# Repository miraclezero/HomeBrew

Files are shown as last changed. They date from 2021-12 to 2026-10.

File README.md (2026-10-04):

# HomeBrew

> Raspberry Pi based hardware and software for independently tracking oral operant self-administration behavior in up to four rats.

HomeBrew coordinates RFID identification, active and inactive spout events, syringe-pump movement, visual indicators, session configuration, and data recording. It is intended for experiments involving orally delivered solutions such as sucrose, alcohol, or opioids.

## Highlights

- Tracks as many as four animals independently
- Uses RFID values to identify commands and animals
- Records active and inactive behavioral events
- Controls a stepper-driven syringe pump
- Supports manual pump positioning with forward and backward controls
- Includes limit-switch protection and LED/pixel-ring feedback
- Stores session settings and pump calibration values
- Provides separate test versions of the main and operant programs
- Includes scripts for network checks and recovery from empty Python files
- Includes OpenSCAD files for project-related fabricated parts

## Repository Layout

```text
HomeBrew/
├── openscad/          # OpenSCAD models for mechanical/fabricated components
├── python/            # Experiment control, hardware control, and data collection
├── utility_script/    # Startup, integrity-check, and maintenance scripts
├── wifi-network/      # Network-related configuration or support files
├── .gitignore
└── README.md
```

## System Overview

The software is divided into two long-running responsibilities:

1. **Session controller** — `main.py` or `main_test.py`
2. **Operant controller** — `operant.py` or `operant_test.py`

The session controller reads a configured command RFID, collects the animals' RFID values, allows pump positioning during setup, and starts the operant controller as a subprocess. The session controller remains active afterward so it can continue identifying animals at the active and inactive spouts.

```mermaid
flowchart TD
    A[Start main.py] --> B[Select session]
    B --> C[Scan command RFID]
    C --> D[pump calibration /optional/]
    D --> E[Adjust pump position]
    E --> F[Scan animal RFID tags]
    F --> G[Disable manual adjustment]
    G --> H[Start operant.py subprocess]
    H --> I[Monitor active and inactive RFID events]
    H --> J[Monitor lick and operant inputs]
    I --> K[Write animal-specific event records]
    J --> K
    J --> L[Deliver configured reward]
```

## Main Software Components

### `main.py` / `main_test.py`

The main entry point is responsible for:

- reading session commands
- scanning animal RFID tags
- managing the pump-positioning period
- launching the operant program
- continuing to monitor RFID input while the operant process runs
- writing active and inactive identification records

The test variant is intended for development or hardware validation. Confirm its behavior against the production script before relying on it during an experiment.

### `operant.py` / `operant_test.py`

The operant program is launched by the main program with the information required for the selected session. It manages operant events and saves recorded data to the corresponding output files.

### `pump_move.py`

This module provides a higher-level `PumpMove` abstraction over Raspberry Pi GPIO control. Its movement method drives the stepper motor forward or backward.

The motor outputs must be disabled after use. Leaving the driver energized can cause unnecessary heating.

### `RatActivityCounter`

Animal activity values, including active and inactive licking or related events, are represented through `RatActivityCounter` instances.

### Pump calibration

The calibration program compensates for changes in the relationship between motor steps and delivered volume. The operator measures the actual amount dispensed, enters that value, and the software recalculates the step setting.

Calibrate whenever the syringe, tubing, mechanical drive, solution, or pump geometry changes, and verify the resulting volume with repeated measurements.

## Experiment Workflow

1. Power the Raspberry Pi and connected hardware.
2. Confirm network status if the installation depends on network access.
3. Start the main program.
4. Scan a command RFID configured in `session_configuration.csv`.
5. Position the syringe pump before finalizing setup.
6. Scan the RFID tag for each animal assigned to the session.
7. Allow the main program to launch the operant process.
8. Monitor the apparatus and verify that active/inactive events are attributed correctly.
9. At the end of the session, confirm that all expected output files were written and safely stop the hardware.

The current logic distinguishes active and inactive RFID input by identifier length: eight characters for active input and ten characters for inactive input. Because identifier length is part of the input protocol, RFID readers and tags must be tested with the exact deployed configuration.

## Configuration

The existing code expects configuration in absolute Raspberry Pi paths.

| File | Purpose |
|---|---|
| `/home/pi/homebrew_config.json` | Stores the device ID, session number/ID, and stepper-motor step size. The session number is incremented when the program starts. |
| `/home/pi/openbehavior/HomeBrew/python/session_configuration.csv` | Defines session information and command RFID mappings. |
| `/home/pi/openbehavior/HomeBrew/python/config.py` | Centralizes directory paths and provides `get_sessioninfo(sessionid)` for reading session data from the CSV file. |

Clone this repository to the Raspberry Pi:

```bash
git clone https://github.com/miraclezero/HomeBrew.git
cd HomeBrew
```

Start the main program

```bash
cd python
python3 main_test.py
```

## Hardware

The documented setup uses the following major components:

- Raspberry Pi
- DRV8834 low-voltage stepper-motor driver
- stepper motor
- external 3–12V power adapter
- Adafruit MPR121 12-key capacitive-touch sensor
- forward and backward limit switches
- forward and backward push buttons
- pixel ring
- active and inactive LEDs
- RFID readers/antennas used by the experiment
- syringe-pump mechanism

## GPIO and Wiring Reference

All GPIO values below use **BCM numbering**, as implied by the existing documentation. Confirm this convention in the code before wiring.

### Stepper Motor Driver — DRV8834

| Driver pin | Connection |
|---|---|
| `VMOT` | Positive terminal of the external power adapter |
| `GND` | Negative terminal of the external power adapter |
| `B2`, `B1`, `A1`, `A2` | Stepper motor wires: black, green, red, and blue, respectively |
| Logic `GND` | Any Raspberry Pi ground pin |
| `M0`, `M1` | GPIO 17 and GPIO 22 |
| `SLP` | Any Raspberry Pi 3.3V pin |
| `STEP` | GPIO 6 |
| `DIR` | GPIO 26 |

The listed motor wire colors may not apply to every motor. Identify coil pairs from the motor documentation or with a meter before connecting the driver.

### Capacitive-Touch Sensor — MPR121

| MPR121 pin | Connection |
|---|---|
| `SCL` | GPIO 3 / I²C clock |
| `SDA` | GPIO 2 / I²C data |
| `3Vo` | Any Raspberry Pi 3.3V pin |
| `GND` | Any Raspberry Pi ground pin |
| `0` | Inactive-contact wire |
| `1` | Active-contact wire |

### Limit Switches

| Switch terminal | Connection |
|---|---|
| Normally Open (`NO`) | Raspberry Pi 5V connection, red wire |
| Forward contact (`C`) | GPIO 24, green wire |
| Backward contact (`C`) | GPIO 23, white wire |

### Manual Pump Buttons

| Control | Connection |
|---|---|
| Forward button | GPIO 5 |
| Backward button | GPIO 27 |
| GND connect with resistor | Any Raspberry Pi ground pin  |

### Pixel Ring

| Pixel-ring pin | Connection |
|---|---|
| `IN` | GPIO 18 |
| `GND` | Any Raspberry Pi ground pin |
| `5V DC` | Any Raspberry Pi 5 V pin |

Check the ring's maximum current demand before powering it from the Raspberry Pi header.

### Status LEDs

| LED | Connection |
|---|---|
| Active LED | GPIO 16 |
| Inactive LED | GPIO 19 |
| GND connect with resistor | Any Raspberry Pi ground pin |

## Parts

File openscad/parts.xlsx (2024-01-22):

Item | Part | Quantity | Supplier | Link
Pump Parts | Pump power | 1 | Amazon | https://www.amazon.com/Belker-Adjustable-Universal-Household-Electronics/dp/B07NKZCWT1
 | NEMA 17 Stepper Motor | 1 | Pololu | https://www.pololu.com/product/2267
 | 12" Actobotics Channel | 1 | ServoCity | https://www.servocity.com/12-0-channel
 | Actobotics Side Tapped Pattern Mount B | 1 | ServoCity | https://www.servocity.com/90-quad-hub-mount-b
 | Actobotics NEMA 17 Stepper Mount | 1 | ServoCity | https://www.servocity.com/nema-17-stepper-motor-mount
 | Pump rod | 1 | Amazon | https://www.amazon.com/uxcell-Stainless-Copper-Thread-Printer/dp/B07R1H5ZMV?s=industrial
 | Rod bearing | 1 | Amazon | https://www.amazon.com/Bearings-Double-Shielded-Miniature-Skateboard/dp/B07H83VV6B
 | Rod coupling | 1 | Amazon | https://www.amazon.com/AFUNTA-Flexible-Couplings-Compatible-Machines/dp/B07JL1QYLS
 | 4 pin connector | 1 | Amazon | https://www.amazon.com/mxuteuk-Female-Connector-Adapter-Electrical/dp/B083GR7FQF
 | 3 pin connector | 1 | Amazon | https://www.amazon.com/BTF-LIGHTING-Connectors-WS2812B-WS2811-WS2812/dp/B01DC0KIT2
 | Limit Switch with Lever 2 Pack | 1 | ServoCity | https://www.servocity.com/spdt-miniature-lever-snap-action-micro-switch-2-pack
Box Parts | Raspberry Pi 3B | 1 | Rasperrypi | https://www.raspberrypi.com/
 | Pi screen | 1 | Dfrobot | https://www.dfrobot.com/product-1784.html
 | Pololu DRV8825 Stepper Motor Driver | 1 | Pololu | https://www.pololu.com/product/2133
 | Touch sensor board | 1 | Adafruit | https://www.adafruit.com/product/1982
 | Button | 1 | Amazon | https://www.amazon.com/Gikfun-12x12x7-3-Tactile-Momentary-Arduino/dp/B01E38OS7K
 | Button board | 1 | Amazon | https://www.amazon.com/LAMPVPATH-Prototype-Breadboard-Universal-Printed/dp/B07JDZDPVQ
 | Led light | 1 | Amazon | https://www.amazon.com/100pcs-Ultra-Bright-Emitting-Diffused/dp/B01GE4WGTS?th=1
 | Rfid scanner | 1 | Amazon | https://www.amazon.com/YARONGTECH-125khz-reader-EM4100-desktop/dp/B078TK8KYL/?th=1
 | connector cables | 1 | Amazon | https://www.amazon.com/Antrader-Breadboard-Dupont-Arduino-Raspberry/dp/B07RXK9SLW?th=1
 | Resistor(200ohm, 1/2w) | 1 | Amazon | https://www.amazon.com/EDGELEC-Resistor-Tolerance-Multiple-Resistance/dp/B07QDXV1KF
Other Parts | 30 cc Syringe 10 pack | 1 | Amazon | https://www.amazon.com/Easy-Glide-30CC-Syringe-Sterile/dp/B08HV25ZN2
 | screw and nuts (#6-32)

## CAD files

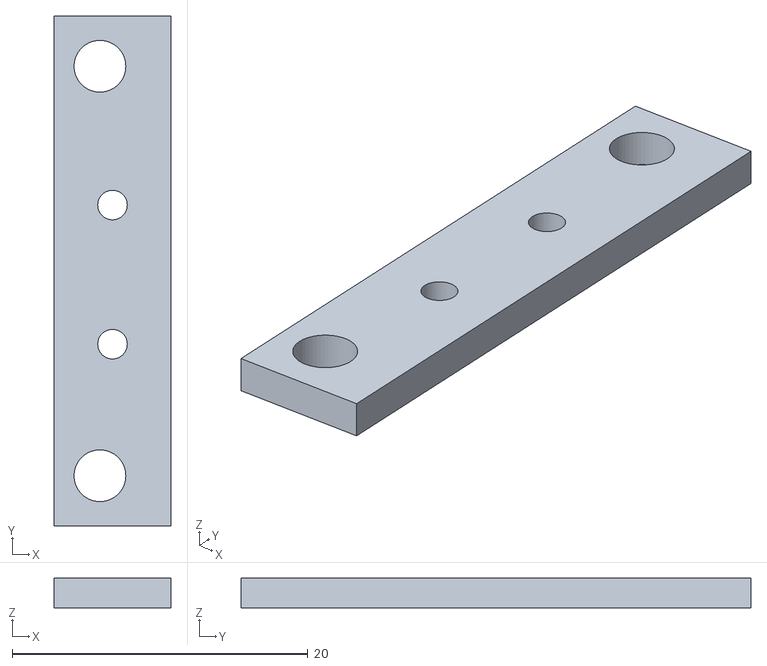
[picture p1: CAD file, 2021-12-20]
openscad/limit_button_mount.stl
7.90 x 34.5 x 2.00

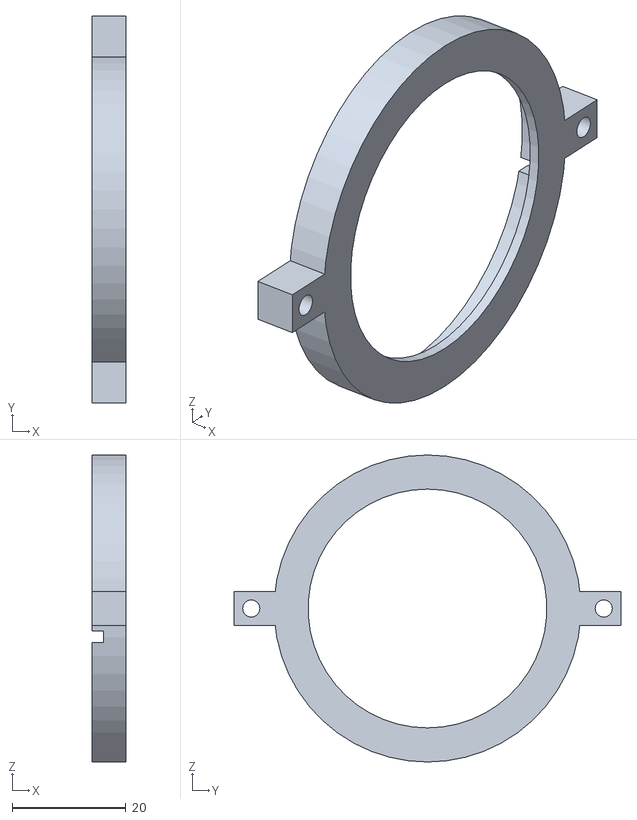
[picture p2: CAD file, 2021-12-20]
openscad/rfid_waterspout_ring_cover.stl
6.00 x 68.0 x 54.0

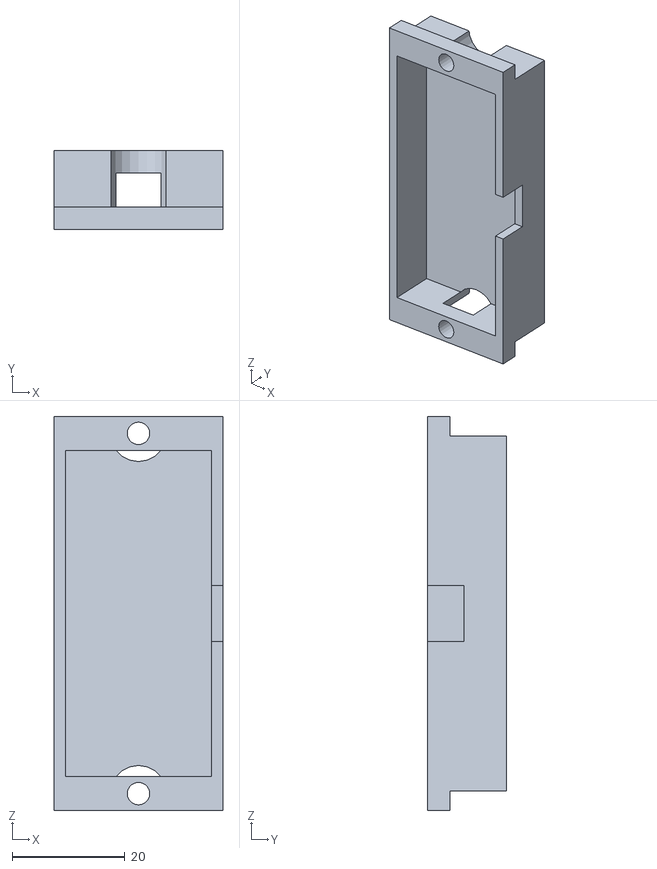
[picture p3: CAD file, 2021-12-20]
openscad/rfid_water_spout_cboard_cover.stl
30.0 x 14.0 x 70.0

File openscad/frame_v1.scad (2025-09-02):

$fn=100;
max_w=210;
max_h=138;
max_d=90;

pw=40;// spout holder width x 
ph=45;// spout holder length y
pg=60;// spout holder height z
//r=10;
fv=0.1; // for better visualization

module corner(ln=20, wd=30 ){ // a negative part for making a round corner 
	difference (){
		cube([wd,wd,ln]);
		translate([0,0,0])
		cylinder(r=wd, h=ln);
	}
}

module outbox(){ // outside box for the frame
	corner_wd=10;
	corner_ln=max_d;
	difference(){
		cube([max_w-fv,max_d-fv,max_h-fv],center=true);
		union(){
			translate([max_w/2-corner_wd, max_d/2, -max_h/2+corner_wd]) rotate([90,90,0]) corner(ln=corner_ln, wd=corner_wd);
			translate([-max_w/2+corner_wd, max_d/2, -max_h/2+corner_wd]) rotate([90,180,0]) corner(ln=corner_ln, wd=corner_wd);
		}
	}
}

module innerbox(){ // inside box for the frame
	inn_w=max_w-8;
	inn_h=max_h-20;
	inn_d=max_d;
	corner_wd=20;
	corner_ln=max_d;
	difference(){
		cube([inn_w-fv,inn_d-fv,inn_h-fv],center=true);
		union(){
			translate([inn_w/2-corner_wd, inn_d/2, -inn_h/2+corner_wd]) rotate([90,90,0]) corner(ln=corner_ln, wd=corner_wd);
			translate([-inn_w/2+corner_wd, inn_d/2, -inn_h/2+corner_wd]) rotate([90,180,0]) corner(ln=corner_ln, wd=corner_wd);
		}
	}
}

module frame(){
	difference () {
		outbox();
		translate([0,4+35,-max_h/2]) cube([max_w-20,max_d-7,max_h/2], center=true);
		translate([0,7+35,-8]) innerbox();//move back wall
        translate([0,7-61.9,-8]) innerbox();//move back wall
        translate([0,4-56,-max_h/2]) cube([max_w-20,max_d-7,max_h/2], center=true);
	}
}

module top_groove(){ // for the top cover
	xw=max_w-5;
	xd=max_d-5;
	difference(){
		union (){
	//		translate([xw/2-.5, xd/2-.5,-5]) corner2();
	//		translate([-xw/2+0.5, -xd/2+0.5,-5]) corner2() ;
	//		translate([-xw/2+0.5, xd/2-0.5,-5]) corner2() ;
	//		translate([xw/2-0.5, -xd/2+0.5,-5]) corner2() ;
			cube([xw, xd, 10], center=true);
		}
		//translate([0,0, -5.6])round_corner_box(r0=5, wd=max_w-24, lg=max_d-24,ht=11);
	}
}

module screw(){
	translate([-30,0,0])rotate([0,90,0]) cylinder(r=1.50, h=35,center=true);
}

module screwset_frame(){

    translate([0,36,-39])screw();
    translate([0,36,39])screw();
    translate([0,-36,-39])screw();
    translate([0,-36,39])screw();

}

module frontpanel(){
    difference(){
        union(){
            cube([69,69,8],center=true);
            translate([0,0,3])cube([84,78,2],center=true);
                translate([0,0,-20])rotate([0,90,0])    screwset_frame();

        }
    	//scale([.8,.95,1])translate([1,0,4])cylinder(r=dia-3,h=14,center=true,$fn=100);
       // translate([0,0,-20])rotate([0,90,0])    screwset_frame();

    }
}


module the_thing (){
	difference(){
		union(){
			difference(){
				//	pw=40;// spout holder width x 
				//	ph=40;// spout holder length y
				//	pg=50;// spout holder height z
				frame();
				union(){
					translate([0,0,max_h/2-4]) top_groove();
					//rotate([90,0,0]) translate([0,0,34]) motion_sensor();
					translate([-max_w/2,0,65]) rotate([0,90,0]) cylinder(r=1.8, h=10); //screw hole for the top cover on the side;
					translate([max_w/2-10,0,65]) rotate([0,90,0]) cylinder(r=1.8, h=10); //screw hole for the top cover on the side; 

					
				}
			}

		}
   translate([max_w/2-44,max_h/2-110+35,5])rotate([0,90,-90]) frontpanel();
   translate([-max_w/2+44,max_h/2-110+35,5])rotate([0,90,-90]) frontpanel();

	}
}
the_thing();

//translate([max_w/2-44,max_h/2-50,13])rotate([0,90,-90]) frontpanel();
//frontpanel();

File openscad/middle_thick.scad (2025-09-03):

$fn=50;


height=59.35 - 2.4;
width=47.60;
thickness=10.65;

topWidth=38.29;
topHeight=23.70;
bottomWidth=31.10;
bottomHeight=height-topHeight;
thickness3=6.57; //thickness of support**



diameter=28.88;



circleThickness=2;
radius=diameter/2 + 1;

smallRecHeight=8.38;
smallRecWidth=3.33;
cuttingWidth=23.59;
cuttingHeight=14.69;
extraHeight = (height - (smallRecHeight + cuttingHeight));
extraWidth = 3.63; // width of axis board

bigCircleDiameter=27.33;
topHalfHeight=29.63;
remaindingHeight=height-topHalfHeight;

hex_nut_diameter=7.89 + 1.6; // +1.6, 
hex_nut_radius=hex_nut_diameter/2;
hex_nut_thickness=3.85;

hex_nut_inner_diameter= 5.8;//5;
hex_nut_inner_radius=hex_nut_inner_diameter/2 + .4;



temp=(thickness/2) - (thickness - thickness3);
offsetFromCenter=19; //19.25; //1.5 // 2.3
hexNutGroveExtraDepth=2;

screwRadius=1.75;
screwDepth=19.35; //increase depth

module part1(){
translate([(width/2) - (topWidth/2) ,(thickness/2) - (thickness3)/2,0]) color("blue") difference(){    
    difference(){
cube([topWidth, thickness3, height], center=true);  

union(){
color("blue") translate([topWidth/2 - (extraWidth/2),0,-extraHeight/2 + ( (height/2) - (smallRecHeight + cuttingHeight) )]) cube([extraWidth,thickness3 ,extraHeight+2.4],center=true);

color("blue") translate([ -(topWidth/2 - (extraWidth/2)),0,-extraHeight/2 + ( (height/2) - (smallRecHeight + cuttingHeight) )]) cube([extraWidth,thickness3 ,extraHeight+2.4],center=true);
}


//translate([0,0,extraHeight - (height/2) - offsetFromCenter]) union(){
//    //-(remaindingHeight/2) + (hex_nut_radius)
//translate([0,5,0]) color("black") rotate([90,0,0]) cylinder(h=hex_nut_thickness/2 + hexNutGroveExtraDepth + 1.3, r=hex_nut_radius,center=true, $fn = 6); //h=thickness3
////-(remaindingHeight/2) + (hex_nut_inner_radius + (hex_nut_radius - hex_nut_inner_radius))
//translate([0, 0,0]) color("red") rotate([90,0,0]) cylinder(h=hex_nut_thickness/2 + 10, r=hex_nut_inner_radius,center=true, $fn = 6);
//}


}
union(){
    translate([0,-((-(thickness3/2)+(thickness3-circleThickness)/2)),(height/2) - (smallRecHeight + cuttingHeight) ]) union(){
translate([0,0,(cuttingHeight/2) + (smallRecHeight)]) cube([cuttingWidth,thickness3 - circleThickness +.1, cuttingHeight],center=true);
                 translate([0,0,smallRecHeight/2]) cube([smallRecWidth,thickness3 - circleThickness+.1,smallRecHeight],center=true);            
}


translate([0,-(thickness3/2 - (circleThickness/2)),(height/2) - (radius)]) color("red")rotate([90,0,0])union(){
        cylinder(h=circleThickness, r=radius, center=true);
        translate([0,radius/2,0])cube([radius*2,radius,circleThickness],center=true);
    }
    
    }

}
}


module part2(){
//translate([0,temp,0]) 
difference(){
translate([0,-5,0]) color("blue")
cube([width,thickness,height],center=true);
//translate([0,(thickness/2) - (thickness - thickness3)/2,0]) color("blue") cube([topWidth,thickness - thickness3,height],center=true);
//
translate([(width/2) - (topWidth/2),(thickness/2) - (thickness3)/2,0]) color("blue") union(){
cube([topWidth, thickness3, height], center=true);   
union(){
color("red") translate([topWidth/2 - (extraWidth/2),0,-extraHeight/2 + ( (height/2) - (smallRecHeight + cuttingHeight) )]) cube([extraWidth,thickness3+20 ,extraHeight+2.4],center=true); //slot **

color("red") translate([ -(topWidth/2 - (extraWidth/2))-0.5,0,-extraHeight/2 + ( (height/2) - (smallRecHeight + cuttingHeight) )]) cube([extraWidth+0.5,thickness3+20,extraHeight+2.4],center=true);
}


//translate([0,0, extraHeight - (height/2)  - offsetFromCenter]) union(){
//    
//translate([0, -temp - (hex_nut_thickness/2) - .8,0]) color("red") rotate([90,0,0]) cylinder(h=hex_nut_thickness/2 + hexNutGroveExtraDepth, r=hex_nut_radius,center=true, $fn = 6);
//
//translate([0, -temp - (hex_nut_thickness/2),0]) color("red") rotate([90,0,0]) cylinder(h=hex_nut_thickness/2 + 7, r=hex_nut_inner_radius,center=true, $fn = 6);
//}


}
}

}

module glueScrews(){
translate([0,0.1,0]) union(){
rotate([90,0,0]) translate([(width/2) - (topWidth/2) - (topWidth/4),-(height/3),-(thickness-screwDepth)/2]) cylinder(h=screwDepth,r=screwRadius,center=true);

rotate([90,0,0]) translate([(width/2) - (topWidth/2) + (topWidth/4),-(height/9),-(thickness-screwDepth)/2]) cylinder(h=screwDepth,r=screwRadius,center=true);
}
}


module modifiedParts(part=1){


difference(){
    
        if(part == 1){
            part1();
        }else if(part == 2){
            part2();
        }
//        part2();    

    
//translate([(width/2) - (topWidth/2),0,extraHeight - (height/2) - offsetFromCenter]) union(){
//    //-(remaindingHeight/2) + (hex_nut_radius)
//    
//    //((hex_nut_thickness/2 + 10)/2)-(hex_nut_thickness/2 + hexNutGroveExtraDepth + 1.3)/2
//
//    
////-(remaindingHeight/2) + (hex_nut_inner_radius + (hex_nut_radius - hex_nut_inner_radius))
//
//
//translate([0,0,0]) color("black") rotate([90,0,0]) cylinder(h=hex_nut_thickness, r=hex_nut_radius,center=true, $fn = 6); //h=thickness3
//
//translate([0, 0,0]) color("red") rotate([90,0,0]) cylinder(h=hex_nut_thickness+ 20, r=hex_nut_inner_radius,center=true, $fn = 6);
//    
//
////    glueScrews();
//}

}
}

//translate([3.5,11,0]) cylinder(d=21.95,h=3.5,$fn=50,center=true);

//translate([(width/2) - (topWidth/2),-(extraHeight - (height/2) - offsetFromCenter),0]) cylinder(d=21.95,h=3.5,$fn=50,center=true);

//union(){
//translate([(width/2) - (topWidth/2),-(extraHeight - (height/2) - offsetFromCenter)-7.75,0]) cylinder(h=15,d=3.75,center=true);
//translate([(width/2) - (topWidth/2) -7.75,-(extraHeight - (height/2) - offsetFromCenter),0]) cylinder(h=15,d=3.75,center=true);
//translate([(width/2) - (topWidth/2) +7.75,-(extraHeight - (height/2) - offsetFromCenter),0]) cylinder(h=15,d=3.75,center=true);
//translate([(width/2) - (topWidth/2) ,-(extraHeight - (height/2) - offsetFromCenter) + 7.75,0]) cylinder(h=15,d=3.75,center=true);
//}


//rotate([-90,0,0]) difference(){
//modifiedParts(1);
//   glueScrews(); 
//}

//rotate([90,0,0]) translate([(width/2) - (topWidth/2),-(0),extraHeight - (height/2) - offsetFromCenter]) cylinder(d=21.95,h=3.5,$fn=50,center=true);

//rotate([90,0,0]) modifiedParts(1);

difference(){
difference(){
rotate([90,0,0]) difference(){

modifiedParts();
//    translate([(width/2) - (topWidth/2),-(extraHeight - (height/2) - offsetFromCenter),0]) cylinder(d=21.95,h=3.5,$fn=50,center=true);
//    glueScrews();
    
}

difference(){
//translate([0,0,.85])
    union(){
//translate([(width/2) - (topWidth/2),-(extraHeight - (height/2) - offsetFromCenter) ,-1.5]) cylinder(d=21.95 + .2,h=3.5,$fn=50,center=true);
//    
//    translate([(width/2) - (topWidth/2),-(extraHeight - (height/2) - offsetFromCenter),0]) cylinder(h=15,d=10 + .2,center=true);
    
    translate([(width/2) - (topWidth/2),-(extraHeight - (height/2) - offsetFromCenter) ,-1.5]) cylinder(d=21.95 + .2,h=3.5,$fn=50,center=true);
    
    translate([(width/2) - (topWidth/2),-(extraHeight - (height/2) - offsetFromCenter),0]) cylinder(h=25,d=10 + .2,center=true);
}


}

}


union(){
translate([(width/2) - (topWidth/2),-(extraHeight - (height/2) - offsetFromCenter)-7.75 ,0]) cylinder(h=25,d=3.75 - .4,center=true);
translate([(width/2) - (topWidth/2) -7.75 ,-(extraHeight - (height/2) - offsetFromCenter),0]) cylinder(h=25,d=3.75 - .4,center=true);
translate([(width/2) - (topWidth/2) ,-(extraHeight - (height/2) - offsetFromCenter) + 7.75 ,0]) cylinder(h=25,d=3.75 - .4,center=true);
translate([(width/2) - (topWidth/2) +7.75 ,-(extraHeight - (height/2) - offsetFromCenter),0]) cylinder(h=25,d=3.75 - .4,center=true);

}

}

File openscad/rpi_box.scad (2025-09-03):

//include <driverPlate.scad>;
$fn=50;


// define global variables (measurments, unit = mm)
lcdWidth = 198 ;
lcdWidthForScrewHolder = 121.4 ;
lcdThickness = 7.91;
lcdHeight = 76.80 ;
baseBoardThickness = 2;//.5;


squareHeight=7.5;
squareWidth=7.5;
squareThickness= 1;//2.5;

screwInnerRadius = 1.5;//2.56;
smallChipWidth = 19.18;
smallChipHeight = 33.32;

heightToScrew = 13.15; //12.88

smallChipThickness = 1.69;
smallChipHoleRadius = 2.42;
screenWidth = 109.8;
screenHeight = 66.4 ;

leftSideInputPortsWidth = 50.67;
leftSideInputPortsHeightFromBase = 21.36;
leftSideInputPortsHeight = 8.05;

endInputPortsHeightFromBase = 30.96;
endInputPortsWidth = 52.37;




overallWidth=77.33 ;
    width=72.91 ;
    protrodingWidth=overallWidth - width;
    protrodingThickness=2.2;
    
    
module base(){
rotate([0,90,0]) color("red") cube([baseBoardThickness+1, lcdWidth, lcdHeight], center=true);
}

module makeRearendWall(head=1){

    overallWidth=78.4;
    width=72.91 -2.5;
    protrodingWidth=overallWidth - width;
    protrodingThickness=2.2;
    
    
//    height=77.33;
//    
//    overallWidth=77.33;
//    width=77.48;//72.91;
//    protrodingWidth=overallWidth - width;
//    protrodingThickness=2.2;
    // front wall
    if(head ==  1){
        translate([0,(lcdWidth/2) + ((baseBoardThickness+1)/2) ,width/2-(baseBoardThickness-1) - 2]) cube([lcdHeight+((baseBoardThickness+1)*2),baseBoardThickness+1,67.4],center=true);    
    }
    //echo((lcdWidthForScrewHolder/2 - (squareHeight/2)) , lcdWidth, lcdWidth - ((lcdWidthForScrewHolder/2 - (squareHeight/2))))
    
    // end wall
    if(head == 0){
//    ((width/2)-((protrodingThickness)/2))    
                translate([0,-(((protrodingThickness) /2)+(lcdWidth/2)),width/2-(baseBoardThickness-1)]) cube([lcdHeight+((baseBoardThickness+1)*2),protrodingThickness,67.41 ],center=true);
    }
    
}



module slider(){
    width = 77.37;
    height = 41.26;
    thickness = 2.11;        
    
    color("red") translate([0,0,lcdHeight/2 + (thickness/2) + (baseBoardThickness/2)]) cube([height, width,thickness],center=true);    
}


module makeTopBottomCover(top=true){
    overallWidth=78.4 ;
    width=72.91 ;
    protrodingWidth=overallWidth - width;
    protrodingThickness=2.2;
   if(top){
       // lcdHeight/2
       
//        (lcdWidth) +(baseBoardThickness+1)*2
   translate([0,0,width - (baseBoardThickness) -1]) cube([lcdHeight+((baseBoardThickness+1) *2), lcdWidth , baseBoardThickness+1],center=true);    
   }
   
   if(!top){
       //+ ((baseBoardThickness+1) *2)
       cube([lcdHeight+((baseBoardThickness+1) *2), (lcdWidth) ,baseBoardThickness+1],center=true);
   }
   
}

cutoff1 = (lcdHeight/2) + (baseBoardThickness/2);
xTempVar = ( (lcdHeight/2) + (baseBoardThickness/2) ) + ( ( (lcdHeight+((baseBoardThickness+1)*2)) )/2 - (cutoff1+ (baseBoardThickness/2) ) ) /2;
yTempVar = -( (lcdWidth/2) + ((baseBoardThickness/2)) + ( ((baseBoardThickness+1)/2) - (baseBoardThickness/2) ) );
zTempVar = 40;

module fourVerticalPoles(topPoles=true, head=true){
    radius = 1.50;//baseBoardThickness/2;
if(topPoles){

if(head){
color("red") translate([xTempVar, yTempVar, zTempVar]) cylinder(r=radius,h=20,center=true);
color("red") translate([-xTempVar, yTempVar, zTempVar]) cylinder(r=radius,h=20,center=true);
}
else{
color("red") translate([xTempVar, -yTempVar, zTempVar]) cylinder(r=radius,h=20,center=true);
color("red") translate([-xTempVar, -yTempVar, zTempVar]) cylinder(r=radius,h=20,center=true);
}

}

if(!topPoles){
color("red") translate([xTempVar,yTempVar,0]) cylinder(r=baseBoardThickness/3,h=20,center=true);
color("red") translate([-xTempVar,yTempVar,0]) cylinder(r=baseBoardThickness/3,h=20,center=true);
}

}

//color("blue") cube([lcdHeight+((baseBoardThickness+1) *2), (lcdWidth + ((baseBoardThickness+1) *2)) ,baseBoardThickness+1],center=true);


depth = squareThickness + 10;
module placeScrewHolder(x=(lcdHeight/2 - (squareWidth/2)) , y=(lcdWidthForScrewHolder/2 - (squareHeight/2)) , z=squareThickness * 1.5 + 15.6, rearEnd=false, flag=1) {
    
    if(rearEnd==false){
    
    translate([x,y,z])
    difference(){
            cube([squareWidth,squareHeight,squareThickness],center=true);
            color("blue") cylinder(r=screwInnerRadius,h=squareThickness,center=true);
    }
    
    }
    
    if(rearEnd==true){
        if(flag == 1){
            translate([x,y,z])
            difference(){
                    cube([squareWidth+1,squareHeight+1,squareThickness],center=true);
                    color("blue") translate([1,-1,0]) cylinder(r=screwInnerRadius+.1,h=squareThickness,center=true);    
            }
        }
            
        if(flag == 2){
            translate([x,y,z])
            difference(){
                    cube([squareWidth+1,squareHeight+1,squareThickness],center=true);
                    color("blue") translate([-1,-1,0]) cylinder(r=screwInnerRadius+.1,h=squareThickness,center=true);            
        }
    }
    }
}

module placeCornerScrewHolder(x=0,y=0,z=0){
    translate([x,y,z])
    difference(){
    color("red") cube([squareWidth,squareHeight,depth],center=true);
    translate([0,0,(depth/2)/2]) color("blue") cylinder(r=screwInnerRadius,h=depth/2,center=true);
    }
}

//placeScrewHolder(x=(lcdHeight/2 - (squareWidth/2)),y=(lcdWidth/2 - (squareHeight/2)),z=((baseBoardThickness+1)/2) + (squareThickness/2) + heightToScrew);


toTranslateX = (lcdHeight/2) - (squareWidth/2);
toTranslateY = (lcdWidth/2) - (squareHeight/2);
//toTranslateZ = (lcdHeight/2) - ((baseBoardThickness+1)/2) - (depth/2);
//toTranslateZ =  depth/2 + ((baseBoardThickness+1)/2) + depth + width/2 + baseBoardThickness+1;
toTranslateZ = 1.5*depth + 1.5*(baseBoardThickness+1) + width/2 + 5.4;//2.5;

toTranslateYBottom = ( (lcdWidth/2) - (depth/2));
toTranslateZBottom =   (squareHeight/2) + ( (baseBoardThickness+1) / 2) + 15;
module makeScrewHolders(){
    
translate([0,0,-1.3]) union(){
    placeScrewHolder(rearEnd=true,flag=2);

    placeScrewHolder(x=-(lcdHeight/2 - (squareWidth/2)), rearEnd=true);
        

    placeScrewHolder(y= -(lcdWidthForScrewHolder/2 - (squareHeight/2) ) );

    placeScrewHolder(x=-(lcdHeight/2 - (squareWidth/2)),y=-(lcdWidthForScrewHolder/2 - (squareHeight/2)));
}
//placeScrewHolder(y=-(lcdWidth/2 - (squareHeight/2)));



// top four screw holder
//placeCornerScrewHolder(x=toTranslateX,y=-toTranslateY,z=toTranslateZ - 2.5);
//placeCornerScrewHolder(x=toTranslateX,y=(lcdWidthForScrewHolder/2 - (squareHeight/2)),z=toTranslateZ - 2.5);
    
//placeCornerScrewHolder(x=-toTranslateX,y=-toTranslateY + 11,z=toTranslateZ - 2.5);        
//placeCornerScrewHolder(x=-toTranslateX,y=(lcdWidthForScrewHolder/2 - (squareHeight/2)),z=toTranslateZ - 2.5); 

 

translate([toTranslateX,-toTranslateYBottom, toTranslateZBottom + heightToScrew]) rotate([90,0,0]) placeCornerScrewHolder();
translate([-toTranslateX,-toTranslateYBottom,toTranslateZBottom + heightToScrew]) rotate([90,0,0]) placeCornerScrewHolder();


//color("green") translate([toTranslateX,-toTranslateYBottom, toTranslateZBottom + heightToScrew + 28.70]) rotate([90,0,0]) placeCornerScrewHolder();
//color("green") translate([-toTranslateX,-toTranslateYBottom,toTranslateZBottom + heightToScrew + 28.70]) rotate([90,0,0]) placeCornerScrewHolder();       
}

extraBoardWidth = (smallChipHeight * 2) + 10;
extraBoardHeight = smallChipWidth + 5;

module extraBaseExtensions(){
// add extra base to hold two additional modules

//color("blue") translate([lcdHeight/2 + (smallChipWidth/2) + 5 ,0,0]) 
    cube([extraBoardHeight, ( (baseBoardThickness+1) *2) + (lcdHeight),(baseBoardThickness+1)], center=true);
}

GPIOSlotsWidth = 50.76/2;
GPIOSlotsHeight = 12.5;


module makeChipSlot(firstSlot=true){
    if(firstSlot){
translate([0,(smallChipHeight/2 + ((baseBoardThickness+1)/2) ),((baseBoardThickness+1) /2)- (smallChipThickness/2)]) cube([smallChipWidth,smallChipHeight,smallChipThickness],center=true);    
        }
        
     if(!firstSlot){
         translate([0,-(smallChipHeight/2 +((baseBoardThickness+1)/2)) ,((baseBoardThickness+1) /2) - (smallChipThickness/2)]) cube([smallChipWidth,smallChipHeight,smallChipThickness],center=true);
     }

}



h1 = (baseBoardThickness+1) - (smallChipThickness);

// extended base with two slots for the two additional sensors.
module sensorSpace(){
    
difference(){
    
difference(){
// extended base (to end)
extraBaseExtensions();
    // making slots for two sensors
    makeChipSlot(firstSlot=true);
    makeChipSlot(firstSlot=false);
}

// make four holes for the purpose of mounting two sensors.
#translate([(smallChipWidth/2) - (smallChipHoleRadius), (smallChipHeight / 2)+ (smallChipHeight/2 + ((baseBoardThickness+1)/2) ) - (smallChipHoleRadius), -(h1/2) - (smallChipThickness - ((baseBoardThickness+1) /2))]) cylinder(r=smallChipHoleRadius - 0.5,h=h1,center=true);
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

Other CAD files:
openscad/spout.scad
openscad/design.scad
openscad/syringe_bottom_holder1.scad
openscad/syringe_bottom_holder2.scad
openscad/syringe_top_and_mid_holder.scad

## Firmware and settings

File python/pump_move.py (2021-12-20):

import signal
import sys
from time import sleep

import RPi.GPIO as GPIO
from gpiozero import InputDevice
from gpiozero import Servo
import pigpio

rotate_dir = 1

GPIO.setwarnings(False)


class PumpMove:
    def __init__(self):
        # GPIO pins numbers
        self.DIR = 26
        self.STEP = 6
        self.SLEEP = 25
        self.MODE = (17, 22)

        # clock-wise and counter clock-wise
        self.CW = 1
        self.CCW = 0

        # GPIO setup
        self.GPIO = GPIO
        self.GPIO.setmode(self.GPIO.BCM)
        self.GPIO.setup(self.DIR, self.GPIO.OUT, initial=self.GPIO.HIGH)
        self.GPIO.setup(self.STEP, self.GPIO.OUT, initial=self.GPIO.HIGH)
        self.GPIO.output(self.DIR, self.CW)

        self.GPIO.setup(self.MODE, self.GPIO.OUT)

        self.RESOLUTION = {
            'Full': (0, 0),
            'Half': (1, 0),
            '1/8': (0, 1),
            '1/16': (1, 1),
        }

        # self.delay = .0209 / 50
        #self.delay = .0209 / 40
        self.delayforward = .0209 / 40
        self.delaybackward = .0209 / 1000
        self.rotate_dir = rotate_dir

    # move forward and backward by providing the direction
    def move(self, direction, steps=150):
        direction_dict = {"forward": self.CW, "backward": self.CCW}

        try:
            self.GPIO.output(self.MODE, self.RESOLUTION['1/8'])
            self.GPIO.output(self.DIR, direction_dict[direction])

            for _ in range(steps):
                self.GPIO.output(self.STEP, self.GPIO.HIGH)
                sleep(self.delayforward)
                self.GPIO.output(self.STEP, self.GPIO.LOW)
                sleep(self.delaybackward)

            self.GPIO.output(self.STEP, self.GPIO.HIGH)
        except KeyError:
            print("please enter a correct direction")

    # release resource. hack for avoid motor driver board overheating issue
    def __del__(self):
        self.GPIO.cleanup(self.MODE)

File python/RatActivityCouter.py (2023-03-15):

import time

class RatActivityCounter():
    def __init__(self, ratid, ratio, rat_label = "unknown"):
        self.ratid = ratid
        self.active_licks = 0
        self.inactive_licks = 0
        self.rewards = 0
        self.touch_counter = 0
        self.syringe_empty = 0
        self.next_ratio = ratio
        self.rat_label = rat_label
        self.last_act_licks = {"time":float(time.time()), "scantime":0}
        self.last_inact_licks = {"time":float(time.time()), "scantime":0}
        self.pumptimedout = False

    # @staticmethod 
    def update_last_licks(self, lick_time, scan_time, act):
        if act:
            self.last_act_licks["time"] = lick_time
            self.last_act_licks["scantime"] = scan_time
        else:
            self.last_inact_licks["time"] = lick_time
            self.last_inact_licks["scantime"] = scan_time
    
    @staticmethod
    def colored_print(ratID, act_count, inact_count, reward_count, timeout):
        print (ratID+ \
            "\x1b[0;32;40m" + \
            ": Active=" + str(act_count)+ \
            "\x1b[0m" + \
            "\x1b[0;33;40m" + \
            " Inactive="+str(inact_count) + \
            "\x1b[0m" + \
            "\x1b[0;32;40m" + \
            " Reward=" +  str(reward_count) + \
            "\x1b[0m" + \
            "\x1b[0;35;40m" + \
            " Timeout: "+ str(timeout) + \
            "\x1b[0m"
            )

    @staticmethod
    def show_data(devID, sesID,sessionLength, schedule, lapsed,
                  rat1,rat2,rat_unknown, phase="progress"):
        if schedule == "pr":
            #minsLeft = int((sessionLength - (time.time() - rat1.last_act_licks["time"])) / 60)
            minsLeft1 = int((sessionLength - (time.time() - rat1.last_act_licks["time"])) / 60)
            minsLeft2 = int((sessionLength - (time.time() - rat2.last_act_licks["time"])) / 60)
            minsLeft3 = int((sessionLength - (time.time() - rat_unknown.last_act_licks["time"])) / 60)
            minsLeft = max (minsLeft1,minsLeft2,minsLeft3)
        else:
            minsLeft = int((sessionLength-lapsed)/60)
        if phase == "final":
            print("{} Session_{}".format(devID, sesID))

        print ("\x1b[0;31;40m" + \
                "[" + str(minsLeft) + " min Left]" + \
                "\x1b[0m")

        for rat in [rat1,rat2,rat_unknown]:
            RatActivityCounter.colored_print(rat.ratid, rat.active_licks,
                                             rat.inactive_licks, rat.rewards,
                                             rat.pumptimedout)
        return time.time() 
    
    def increase_syringe_empty(self):
        self.syringe_empty += 1

    def incr_rewards(self):
        self.rewards += 1
    # all active licks
    def incr_active_licks(self):
        self.active_licks += 1

    def incr_inactive_licks(self):
        self.inactive_licks +=  1
    # counts are active licks but only those contribute to the next reward (i.e., not during time out and resets after a reward is given
    def incr_touch_counter(self):
        self.touch_counter += 1 

    def reset_touch_counter(self):
        self.touch_counter = 0

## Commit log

2021-12-21 Update operant_test.py
    switch to homebrew
2022-01-13 push syringe to wet spout
2022-02-25 add FR 2mins rfid for quick device test
    [session_configuration.csv]
2022-04-13 add 16 hours VR 10 sessions IDs
    [session_configuration.csv]
2022-05-10 Change threshold of touch sensor
2022-06-21 update pump files
    [pump_mid.stl, pump_top.stl]
2022-08-08 add vr 5 key
    [session_configuration.csv]
2022-10-24 add PR key
    [session_configuration.csv]
2022-10-24 update PR ratio
    [session_configuration.csv]
2022-10-24 pr key update
    [session_configuration.csv]
2022-12-12 add vrwl key
    [session_configuration.csv]
2023-01-03 update all VR to timeout 10 with ratio 10
    [session_configuration.csv]
2023-01-03 change VR5 to timeout 10 with ratio 5
    [session_configuration.csv]
2023-01-10 add FR 1To1 and FR 1To0 key
    [session_configuration.csv]
2023-01-10 add VR 5To1 key
    [session_configuration.csv]
2023-01-10 add VR 5TO3 key
    [session_configuration.csv]
2023-02-06 Add VR 5TO3 with 50 limits
    [session_configuration.csv]
2023-02-06 change to 2hours vrwl with 50 limits
    [session_configuration.csv]
2023-02-23 add PR3 key
    [session_configuration.csv]
2023-06-26 add 16hrs Vr5To3 key
    [session_configuration.csv]
2023-09-08 add vr5t3 2h key
    [session_configuration.csv]
2024-01-22 add parts list
    [parts.xlsx]
2025-11-12 Update and rename spountcover.scad to spout.scad
    [spout.scad]
2025-11-12 Update and rename openscad/endPiece.scad to syringe_top_and_mid_holder.scad
    [syringe_top_and_mid_holder.scad]
2025-11-12 Update and rename design.scad to syringe_bottom_holder1.scad
    [syringe_bottom_holder1.scad]
2025-11-12 Update and rename middle_thick.scad to syringe_bottom_holder2.scad
    [syringe_bottom_holder2.scad]
2025-12-03 add FR1to3 for test
    [session_configuration.csv]
